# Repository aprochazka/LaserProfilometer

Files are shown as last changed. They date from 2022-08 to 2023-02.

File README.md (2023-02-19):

# LaserProfilometer - Power Supply

## BP VUT FIT 2022 - Linear Laser Profilometer

#### Power to diode can be adjusted by applying voltage to VSET (0V = 0mA on LASER, 3V = 70mA on LASER) or by sending PWM signal to VSET

pwrSupply

#### !! Always have diode connected to LASER connector when applying voltage to VSET or VIN (5V) !!

| Connector | Max Value |
| --- | --- |
| VSET (IN) | 3V |
| LASER (OUT) | 70mA |
| VIN (IN) | 5V |

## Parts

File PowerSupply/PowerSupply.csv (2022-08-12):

Source: | C:\BP\LinearLaserProfilometer\PowerSupply\PowerSupply.kicad_sch
Date: | 8/4/2022 12:57:54 PM
Tool: | Eeschema (6.0.7)
Generator: | C:\Program Files\KiCad\6.0\bin\scripting\plugins/bom_csv_grouped_by_value_with_fp.py
Component Count: | 9
Ref | Qnty | Value | Cmp name | Footprint | Description | Vendor
C1, | 1 | 10uF | C |  | Unpolarized capacitor
D1, | 1 | D_Schottky | D_Schottky |  | Schottky diode
J1, | 1 | POWER | Conn_01x02_1 | Connector_PinHeader_2.54mm:PinHeader_1x02_P2.54mm_Vertical | Generic connector, single row, 01x02, script generated (kicad-library-utils/schlib/autogen/connector/)
J2, | 1 | CONTROL | Conn_01x02_2 | Connector_PinHeader_2.54mm:PinHeader_1x02_P2.54mm_Vertical | Generic connector, single row, 01x02, script generated (kicad-library-utils/schlib/autogen/connector/)
J3, | 1 | LASER | Conn_01x02 | Connector_PinHeader_2.54mm:PinHeader_1x02_P2.54mm_Vertical | Generic connector, single row, 01x02, script generated (kicad-library-utils/schlib/autogen/connector/)
L1, | 1 | 33uH | L |  | Inductor
R1, | 1 | 1.4R | R |  | Resistor
R2, | 1 | 10K | R |  | Resistor
U0, | 1 | AL8861Y-13 | AL8861Y-13 | Package_TO_SOT_SMD:SOT-89-5

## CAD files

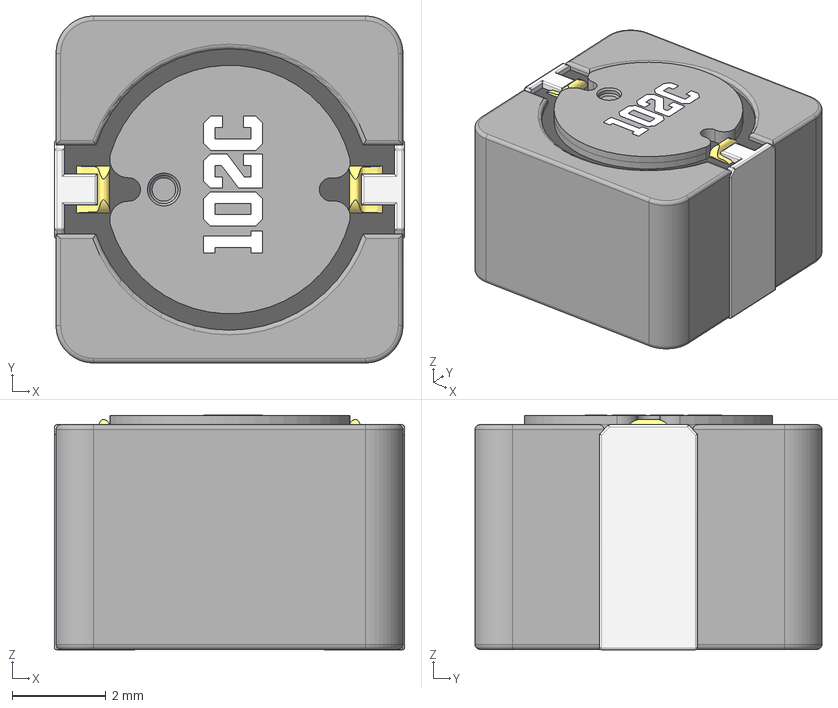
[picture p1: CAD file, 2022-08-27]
PowerSupply/3D_models/INDUCTOR_73x73h5.step
7.47 x 7.40 x 5.00 mm
Fill
Pins
Copper
Pins001
Copper001
Text

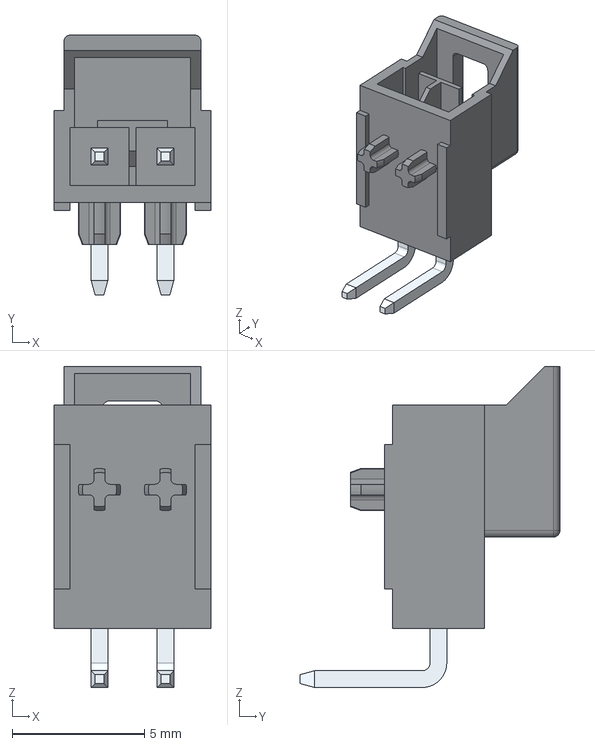
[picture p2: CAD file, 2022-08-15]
PowerSupply/3D_models/Molex_Nano-Fit_105313-xx02_1x02_P2.50mm_Horizontal.step
5.94 x 9.84 x 12.2 mm

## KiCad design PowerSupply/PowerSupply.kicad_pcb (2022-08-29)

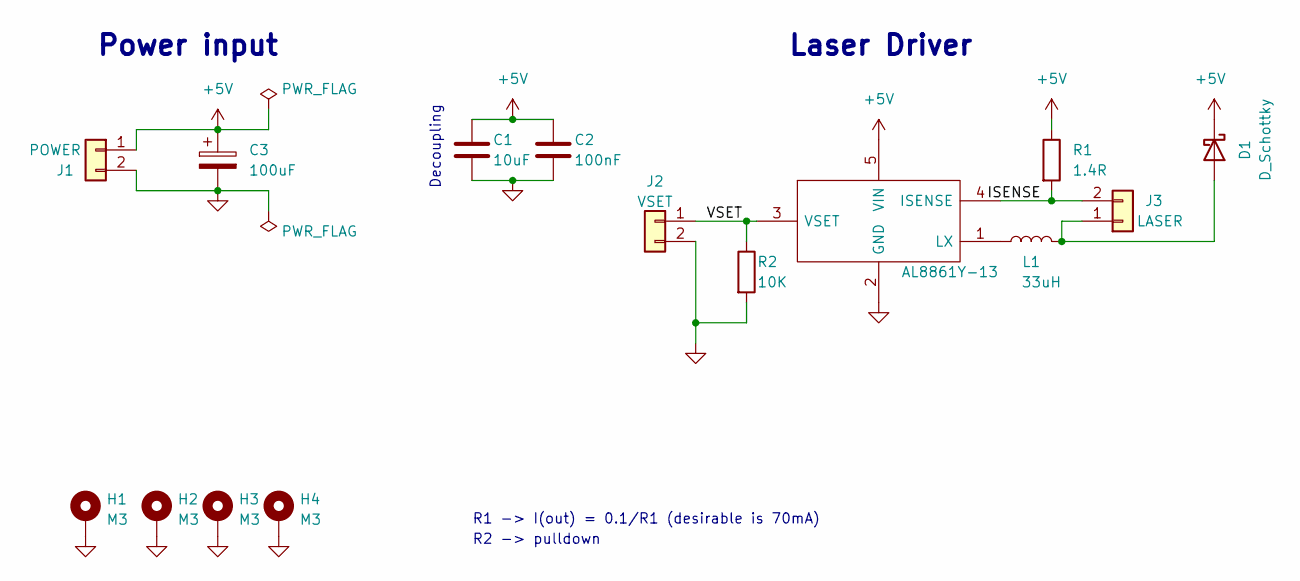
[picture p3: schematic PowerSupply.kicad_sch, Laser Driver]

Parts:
C1: 10uF; C_1206_3216Metric_Pad1.33x1.80mm_HandSolder; Manufacturer_Part_Number NOSA106M006R0800; Mouser Part Number 581-NOSA106M006R0800
C2: 100nF; C_1206_3216Metric_Pad1.33x1.80mm_HandSolder; Manufacturer_Part_Number 12066D104KAT4A; Mouser Part Number 581-12066D104KAT4A
C3: 100uF; CP_Elec_5x5.3; Manufacturer_Part_Number 865080142007; Mouser Part Number 710-865080142007
D1: D_Schottky; D_SOD-123F; Manufacturer_Part_Number SL02-GS08; Mouser Part Number 78-SL02
H1, H2, H3, H4: M3; MountingHole_3.2mm_M3_Pad_Via
J1: POWER; Molex_Nano-Fit_105313-xx02_1x02_P2.50mm_Horizontal
J2: VSET; Molex_Nano-Fit_105313-xx02_1x02_P2.50mm_Horizontal
J3: LASER; Molex_Nano-Fit_105313-xx02_1x02_P2.50mm_Horizontal
L1: 33uH; 4800S; Manufacturer_Part_Number 48330SC; Mouser Part Number 580-48330SC
R1: 1.4R; R_1206_3216Metric_Pad1.30x1.75mm_HandSolder; Manufacturer_Part_Number CRCW12061R40FKEAHP; Mouser Part Number 71-CRCW12061R40FKEAH
R2: 10K; R_1206_3216Metric_Pad1.30x1.75mm_HandSolder; Manufacturer_Part_Number CRMA1206AF10M0DKEF; Mouser Part Number 71-CRMA1206AF10M0DKF
U0: AL8861Y-13; SOT-89-5; Mouser Part Number 621-AL8861Y-13

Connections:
+5V: C1.1, C2.1, C3.1, D1.1 (K), J1.1, R1.1, U0.5 (VIN)
/ISENSE: J3.2, R1.2, U0.4 (ISENSE)
/VSET: J2.1, R2.1, U0.3 (VSET)
GND: C1.2, C2.2, C3.2, H1.1, H2.1, H3.1, H4.1, J1.2, J2.2, R2.2, U0.2 (GND)
unnamed: D1.2 (A), J3.1, L1.2
unnamed: L1.1, U0.1 (LX)

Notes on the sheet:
R2 -> pulldown
R1 -> I(out) = 0.1/R1 (desirable is 70mA)
Decoupling
Laser Driver
Power input

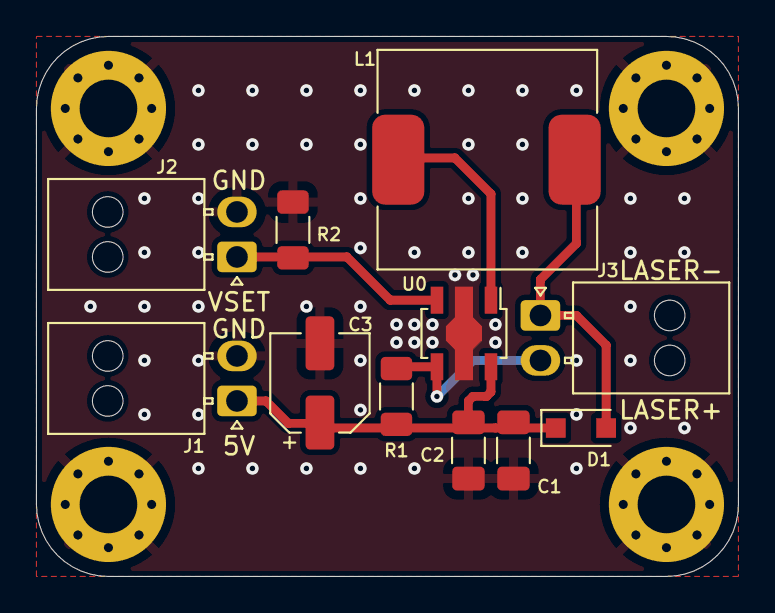
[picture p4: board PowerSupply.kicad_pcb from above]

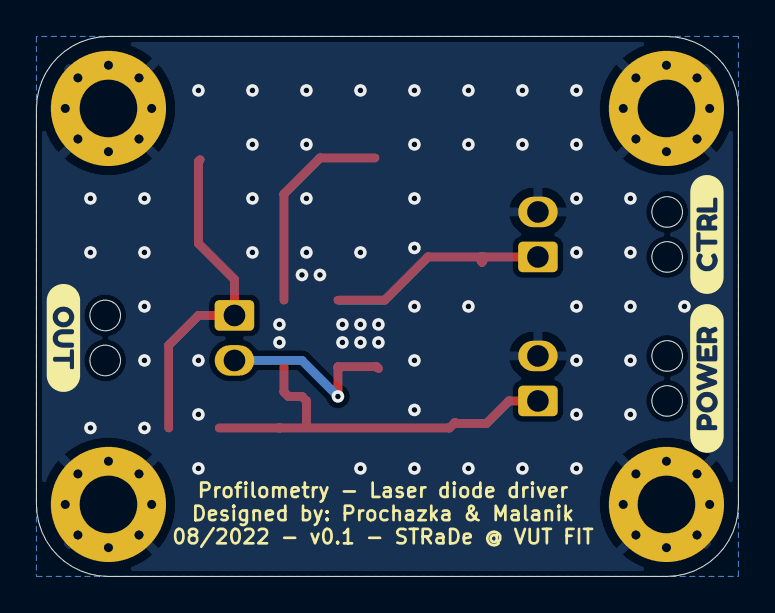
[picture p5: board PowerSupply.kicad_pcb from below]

Board: 2 copper layers, 39.0 x 30.0 mm, 18 parts (3 on the bottom side), 6 nets.

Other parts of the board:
kibuzzard-630C9A2E: G***; kibuzzard-630C9A2E
kibuzzard-630C9A4C: G***; kibuzzard-630C9A4C
kibuzzard-630C99F1: G***; kibuzzard-630C99F1

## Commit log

2022-08-02 Add first files
    Filenames are to be changed, need to create folder structure.
    [bp.kicad_pcb, bp.kicad_sch]
2022-08-03 Update folder structure + update power supply sch
    [PowerSupply.kicad_sch]
2022-08-04 update powersupply
    edit resistor R1 (controling current) value, add pulldown on VSET, add descriptions
    [PowerSupply.kicad_sch]
2022-08-04 edit footprints
    [PowerSupply.kicad_sch]
2022-08-12 Add footprints
    [PowerSupply.csv, PowerSupply.kicad_pcb, PowerSupply.kicad_sch]
2022-08-12 Basic pcb layout
    [PowerSupply.kicad_pcb]
2022-08-12 Remove initial commit files
    [bp.kicad_pcb, bp.kicad_sch]
2022-08-15 Review: 1st round - Schema & PCB - General modifications
    All comments in design files, more on chat
    [Molex_Nano-Fit_105313-xx02_1x02_P2.50mm_Horizontal.step, PowerSupply.kicad_pcb, PowerSupply.kicad_sch]
2022-08-27 Resolved first review, Routing
    [INDUCTOR_73x73h5.step, PowerSupply.kicad_pcb, PowerSupply.kicad_sch]
2022-08-28 Review: 2st round - PCB - General routing (planes, vias, pads routing)
    [PowerSupply.kicad_pcb, PowerSupply.kicad_sch]
2022-08-29 Resolve comments in second review
    [PowerSupply.kicad_pcb, PowerSupply.kicad_sch]
2022-08-29 update stitching
    [PowerSupply.kicad_pcb]
2022-08-29 Connection labels
    [PowerSupply.kicad_pcb]
2022-08-29 edit version
    [PowerSupply.kicad_pcb, PowerSupply.kicad_sch]
